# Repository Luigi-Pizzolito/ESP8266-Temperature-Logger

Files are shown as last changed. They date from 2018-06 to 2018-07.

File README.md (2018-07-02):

Add pictures from instructable
# ESP8266 Temperature Logger (in development)
A simple wireless temperature logger. Publishes data via GET requests.

- [ESP8266 Temperature Logger (in development)](#esp8266-temperature-logger-in-development)
    - [Planned Features (And Progress)](#planned-features-and-progress)
    - [About](#about)
        - [Uploading Data](#uploading-data)
        - [Power Saving](#power-saving)
        - [Configuration](#configuration)
    - [Useful Links and References](#useful-links-and-references)

## Planned Features (And Progress)
 - [X] Uploads
 - [X] Power Saving
 - [X] Configuration

## About
Designed to be simple and easy to use. Will simply log temperature at the specified interval and send the values over to a IOT Server.

### Uploading Data
To keep things simple, this data logger makes HTTP GET requests to upload it's data. It passes the temperature reading and supply voltage as arguments.

This makes for a extremely neat setup if it is paired with Google Forms, Google Sheets and IFTTT.
By opening up a Google Form, with text fields for temperature and voltage. You can link that form to a Google sheet, which automatically updates with every form response and can graph your data. Finally, submitting a form is done via a GET request, be it a complicated one. Therefore using IFTTT's maker webhooks. We can create an applet that takes a simple GET request from our ESP Datalogger and passes the values down to another request that submits the Google forms. Once this is set up, it works like a charm. Plus, live updates!

### Power Saving
Since this is a logger and will almost certainly spend most of it's time laying around not doing anything; we wan't to make it consume the least power as possible. This means that as soon as data is uploaded it immediatly goes back to deep sleep. Deep sleep turns all the ESP's internal modules off except for the RTC which wakes it back up. This plus removing the pesky red power led on a ESP-01 module gives excellent power saving.
But there's a catch, for the RTC to reset and wake up the ESP it needs an external interrupt. This means that we have to connect GPIO16(D0) to RESET. This would be easy on a ESP-12E, ESP-07 or NodeMCU but GPIO16 is not broken out on a ESP-01. So in order to access it you will have to attempt to solder a thin wire to the pin directly on the miniscule ESP chip. This is certainly the hardest part of making this logger, but it is do-able with just a standard soldering iron and a lot of patience.
By changing the interval between logs you can also improve the battery life. The longer the interval the longer it will last, but the fewer readings. You need to choose a interval large enough so that the power consumption is small, but small enough so that you can see any trends on the graph/data.

### Configuration
GPIO_3 or the RX Pin when connected to GND during start up enters config. mode. Where an access point called "ESP_Logger" with the password "wifilogger" is created. By connecting to it and visiting 192.168.4.1 you can open the configuration page and edit all the settings for your logger. Additionally you can edit the file system on 192.168.4.1/edit

## Useful Links and References
- ESP Info
    - Pinouts
        - [ESP-12 Pinout](https://esp8266.github.io/Arduino/versions/2.0.0/doc/esp12.png)
        - [ESP-01 Pinout](https://os.mbed.com/media/uploads/sschocke/esp8266-pinout_etch_copper_top.png)
    - General Guides
        - [Sparkfun Guide](https://learn.sparkfun.com/tutorials/esp8266-thing-hookup-guide/using-the-arduino-addon)
        - [Excellent Beginner's Guide](https://github.com/tttapa/ESP8266)
- GitHub Markdown Info
    - [Formatting and Syntax](https://help.github.com/articles/basic-writing-and-formatting-syntax/)
    - [Emoji Cheat Sheet](https://www.webpagefx.com/tools/emoji-cheat-sheet/)

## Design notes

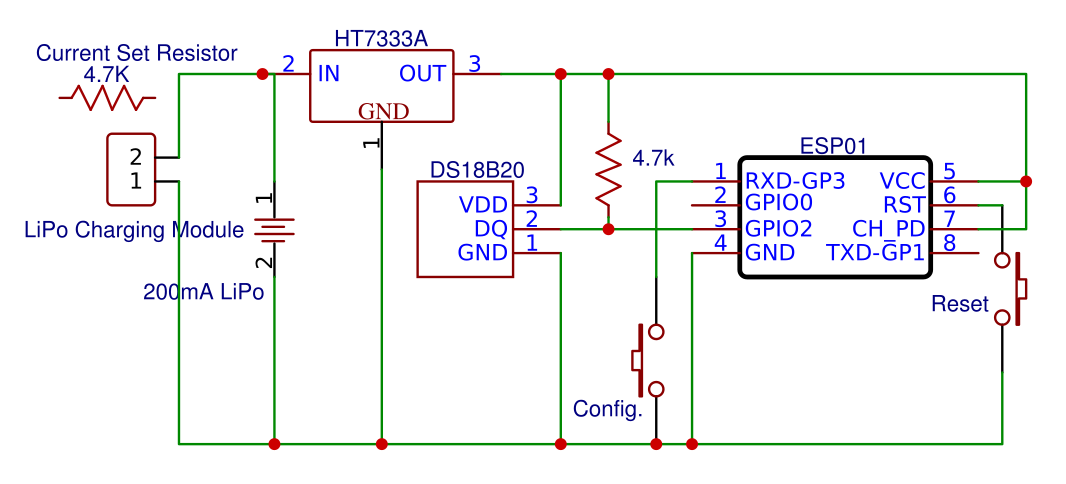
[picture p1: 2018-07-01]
Schematic/Schematic_IFTTT-Dash-Button_New-Schematic_20180702032907.png

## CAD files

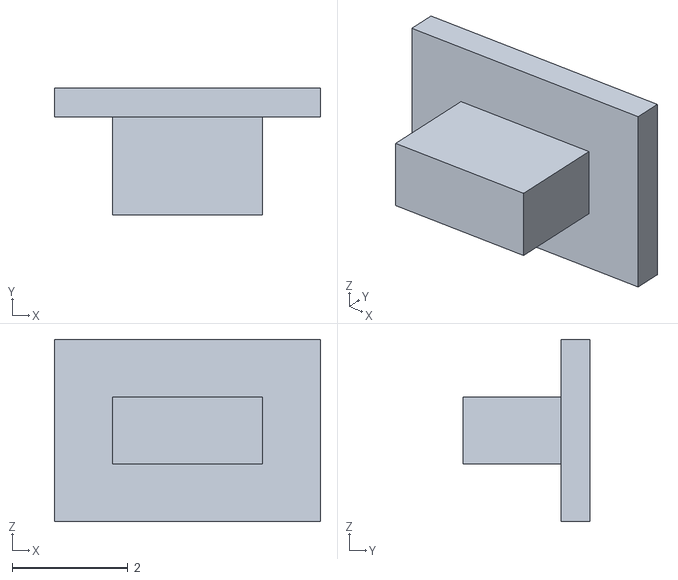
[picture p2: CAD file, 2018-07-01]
3D Printed Case/buttons.stl
4.60 x 2.20 x 3.15

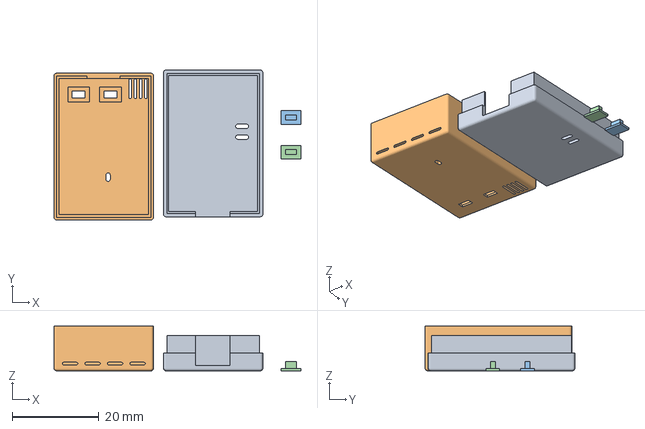
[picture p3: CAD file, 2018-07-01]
3D Printed Case/TinyTemp_Case.3mf
57.1 x 34.6 x 10.4 mm

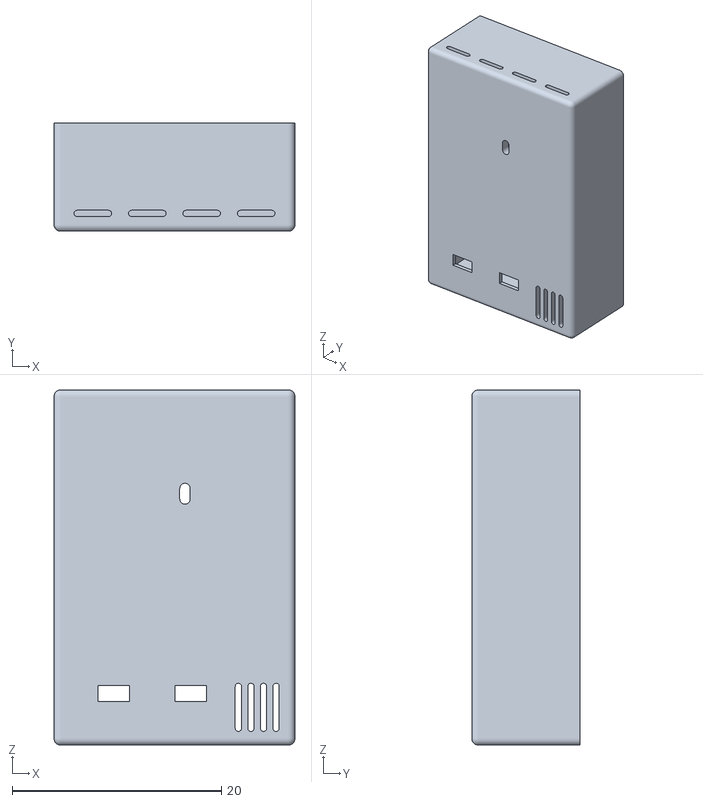
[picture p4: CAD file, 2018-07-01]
3D Printed Case/top_case.stl
23.0 x 10.4 x 33.9

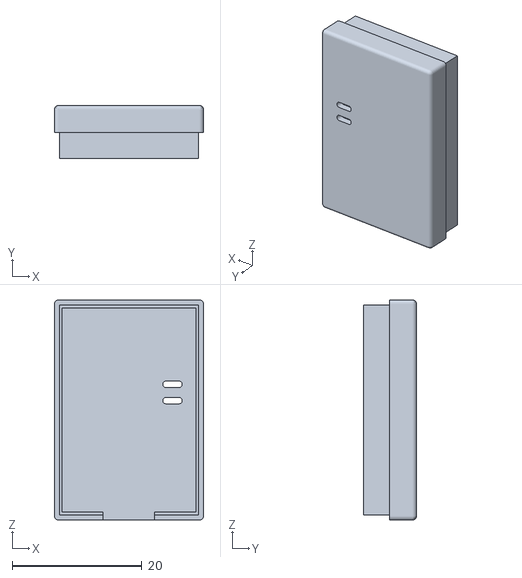
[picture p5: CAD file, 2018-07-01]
3D Printed Case/bottom_case.stl
23.0 x 8.15 x 33.9

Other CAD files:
3D Printed Case/case v18.f3d

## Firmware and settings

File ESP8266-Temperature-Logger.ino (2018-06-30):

/*
   Libraries needed
*/
//Normal Mode
#include <ESP8266WiFi.h>
#include <ArduinoJson.h>
//Config. Mode
#include <WiFiClient.h>
#include <ESP8266WebServer.h>
#include <FS.h>
//Temperature Sensing.
#include <OneWire.h>

/*
   Configurable Settings

   Connect CONFIG_PIN(Default GPIO_03[RX]) to GND during startup to enter Config. Mode:
      1. Connect to 'ESP_Logger' WiFi Access Point, with the password 'wifilogger'
      2. Visit http://192.168.4.1 to open the configuration page, or  http://192.168.4.1/edit to see the filesystem.
      3. After seeting your values, click on the 'Save' button then the 'Restart'
      4. Your logger is now configured.
*/
String ssid;
String password;
String host;
String url;
int wc_p;         // max. time in seconds to connect to wifi, before giving up
int gr_p;         // max. times of attemps to perform GET request, before giving up
bool s_vcc;       //wether to send VCC voltage as a parameter in the url request.
bool is_ip;       //wether host adress is IP
String vcc_parm;  //parameter to pass VCC voltage by.
String temp_parm; //parameter to pass temperature by.
long sleepTime;

//temp Sensing
float celsius;

/*
   System Variables
*/
#define NOT_DEBUG //wether to enable debug or to show indication lights instead
//Normal Mode
int failCount = 0;
ADC_MODE(ADC_VCC);
bool su_mode = true;
//Config. Mode
#define CONFIG_PIN 3
ESP8266WebServer server(80);
File fsUploadFile;
const char *APssid = "ESP_Logger";
const char *APpass = "wifilogger";
//Temp Sensing
OneWire ds(2); // on pin 2 (a ~4.7K resistor is necessary)

void setup()
{
  //start serial monitor, SPIFFS and Config. Pin
  pinMode(16, WAKEUP_PULLUP);
  WiFi.persistent(false);
  Serial.begin(115200);
  pinMode(CONFIG_PIN, INPUT_PULLUP);
  delay(10);
  SPIFFS.begin();
  Serial.println();
  Serial.println("Logger Booting...");

  //read Config. Pin
  su_mode = !digitalRead(CONFIG_PIN);
  if (su_mode)
  {

//start Config. Mode
#ifdef NOT_DEBUG
    pinMode(LED_BUILTIN, OUTPUT);
    digitalWrite(LED_BUILTIN, LOW);
#endif
    Serial.println("Entering Config. Mode!");

    //start WiFi Access Point
    Serial.println("Configuring Access Point...");
    WiFi.mode(WIFI_AP_STA);
    WiFi.softAP(APssid, APpass);

    IPAddress myIP = WiFi.softAPIP();
    Serial.print("AP IP Address: ");
    Serial.println(myIP);

    //start HTTP server

    //edit pages
    server.on("/list", HTTP_GET, handleFileList);
    server.on("/edit", HTTP_GET, []() {
      if (!handleFileRead("/edit.htm"))
        server.send(404, "text/plain", "File Not Found");
    });
    server.on("/edit", HTTP_PUT, handleFileCreate);
    server.on("/edit", HTTP_DELETE, handleFileDelete);
    server.on("/edit", HTTP_POST, []() { server.send(200, "text/plain", ""); }, handleFileUpload);

    //pages from SPIFFS
    server.onNotFound([]() {
      if (!handleFileRead(server.uri()))
      {
        server.send(404, "text/plain", "File Not Found");
      }
    });

    //temp serving page
    server.on("/temp", HTTP_GET, []() { celsius = getTemp(); server.send(200, "text/plain", String(celsius)); });
    server.on("/temp/", HTTP_GET, []() { celsius = getTemp(); server.send(200, "text/plain", String(celsius)); });

    server.begin();
    Serial.println("HTTP Server Started");
  }
  else
  {
    //start Normal Mode
    Serial.println("SPIFFS Content: ");
    {
      Dir dir = SPIFFS.openDir("/");
      while (dir.next())
      {
        String fileName = dir.fileName();
        size_t fileSize = dir.fileSize();
        Serial.printf("FS File: %s, size: %s\n", fileName.c_str(), formatBytes(fileSize).c_str());
      }
      Serial.printf("\n");
    }

    //read and parse config.json from SPIFFS
    readConfig();

    //connect to WiFi
    Serial.println();
    Serial.println();
    Serial.print("Connecting to ");
    Serial.println(ssid);

    WiFi.mode(WIFI_STA);
    WiFi.begin(ssid.c_str(), password.c_str());

    while (WiFi.status() != WL_CONNECTED)
    {
      delay(500);
      Serial.print(".");
      //if we are taking too long to connect to WiFi give up.
      failCount++;
      if (failCount == wc_p * 2)
      {
        Serial.print("Session Terminated. Giving up After ");
        Serial.print(wc_p);
        Serial.println(" Tries Connecting to WiFi.");
        delay(20);
        fail();
        sleepNow();
      }
    }

    Serial.println("");
    Serial.println("WiFi connected");
    Serial.print("IP Address: ");
    Serial.println(WiFi.localIP());
    failCount = 0;
  }
}

void loop()
{
  if (su_mode)
  {
    server.handleClient();
  }
  else
  {
    //if we have tried too many times to make a GET Request give up.
    ++failCount;
    if (failCount == gr_p + 1)
    {
      Serial.print("Session Terminated. Giving up After ");
      Serial.print(gr_p);
      Serial.println(" Tries Doing the GET Request.");
      delay(20);
      fail();
      sleepNow();
    }

    Serial.print("Try: ");
    Serial.println(failCount);
    Serial.print("Connecting to ");
    Serial.println(host);

    //try to connect to the host with TCP
    WiFiClient client;
    const int httpPort = 80;
    if (is_ip)
    {
      IPAddress addr;
      if (addr.fromString(host))
      {
        if (!client.connect(addr, httpPort))
        {
          //try again if the connection fails.
          Serial.println("Connection To IP Failed");
          delay(10);
          return;
        }
      }
      else
      {
        Serial.println("Failed to Convert IP String to IP Address.");
        while (1)
          ;
      }
    }
    else
    {
      if (!client.connect(host.c_str(), httpPort))
      {
        //try again if the connection fails.
        Serial.println("Connection Failed");
        delay(10);
        return;
      }
    }

    //create the URI for the request
    url += "?";

    if (s_vcc)
    {
      //read vcc
      url += vcc_parm;
      url += "=";
      uint32_t getVcc = ESP.getVcc();
      String VccVol = String((getVcc / 1000U) % 10) + "." + String((getVcc / 100U) % 10) + String((getVcc / 10U) % 10) + String((getVcc / 1U) % 10);
      url += VccVol;
      url += "&";
    }
    //read temperature
    url += temp_parm;
    url += "=";
    celsius = getTemp();
    url += String(celsius);

    //request url to server
    Serial.print("Requesting URL: ");
    Serial.println(url);

    client.print(String("GET ") + url + " HTTP/1.1\r\n" +
                 "Host: " + host.c_str() + "\r\n" +
                 "Connection: close\r\n\r\n");

    unsigned long timeout = millis();
    while (client.available() == 0)
    {
      if (millis() - timeout > 60000)
      {
        //give up if the server takes too long to reply.
        Serial.println(">>> Client Timeout !");
        client.stop();
        //return;
        sleepNow();
      }
    }

    //print response to serial
    while (client.available())
    {
      String line = client.readStringUntil('\r');
      Serial.print(line);
    }
    //finish request and close connections
    client.stop();
    Serial.println();
    Serial.println("Closing Connection");

    //enter Deep Sleep
    // Serial.println("Entering Deep Sleep");
    delay(100);
    yay();
    sleepNow();
  }
}

/*
   Universal Functions
*/

//temp reading
float getTemp()
{
  byte i;
  byte present = 0;
  byte type_s;
  byte data[12];
  byte addr[8];
  float celsius, fahrenheit;
  int failCountWire = 0;

  if (!ds.search(addr))
  {
    failCountWire++;
    if (failCountWire == 5)
    {
      Serial.print("Reding Terminated. Giving up After 5 Tries Reading Sensor...");
      delay(20);
      fail();
      sleepNow();
    }
    Serial.println("No more addresses.");
    Serial.println();
    ds.reset_search();
    delay(250);
    // return;
  }

  Serial.print("ROM =");
  for (i = 0; i < 8; i++)
  {
    Serial.write(' ');
    Serial.print(addr[i], HEX);
  }

  if (OneWire::crc8(addr, 7) != addr[7])
  {
    Serial.println("CRC is not valid!");
    delay(20);
    fail();
    sleepNow();
    // return;
  }
  Serial.println();

  // the first ROM byte indicates which chip
  switch (addr[0])
  {
  case 0x10:
    Serial.println("  Chip = DS18S20"); // or old DS1820
    type_s = 1;
    break;
  case 0x28:
    Serial.println("  Chip = DS18B20");
    type_s = 0;
    break;
  case 0x22:
    Serial.println("  Chip = DS1822");
    type_s = 0;
    break;
  default:
    Serial.println("Device is not a DS18x20 family device.");
    delay(20);
    fail();
    sleepNow();
  }

  ds.reset();
  ds.select(addr);
  ds.write(0x44, 1); // start conversion, with parasite power on at the end

  delay(1000); // maybe 750ms is enough, maybe not
  // we might do a ds.depower() here, but the reset will take care of it.

  present = ds.reset();
  ds.select(addr);
  ds.write(0xBE); // Read Scratchpad

  Serial.print("  Data = ");
  Serial.print(present, HEX);
  Serial.print(" ");
  for (i = 0; i < 9; i++)
  { // we need 9 bytes
    data[i] = ds.read();
    Serial.print(data[i], HEX);
    Serial.print(" ");
  }
  Serial.print(" CRC=");
  Serial.print(OneWire::crc8(data, 8), HEX);
  Serial.println();

  int16_t raw = (data[1] << 8) | data[0];
  if (type_s)
  {
    raw = raw << 3; // 9 bit resolution default
    if (data[7] == 0x10)
    {
      // "count remain" gives full 12 bit resolution
      raw = (raw & 0xFFF0) + 12 - data[6];
    }
  }
  else
  {
    byte cfg = (data[4] & 0x60);
    // at lower res, the low bits are undefined, so let's zero them
    if (cfg == 0x00)
      raw = raw & ~7; // 9 bit resolution, 93.75 ms
    else if (cfg == 0x20)
      raw = raw & ~3; // 10 bit res, 187.5 ms
    else if (cfg == 0x40)
      raw = raw & ~1; // 11 bit res, 375 ms
    //// default is 12 bit resolution, 750 ms conversion time
  }
  celsius = (float)raw / 16.0;
  return celsius;
}

//enter deep Sleep
void sleepNow()
{
  yield();
  //delay(120000);
  WiFi.disconnect();
  WiFi.mode(WIFI_OFF);
  // WiFi.forceSleepBegin();

  Serial.println("Entering Deep sleep...");
  delay(300);
  yield();
  ESP.deepSleep(sleepTime * 60 * 1000000, WAKE_RF_DEFAULT);
  delay(1000);
}

void fail()
{
  //something has gone wrong, blink an indicator on the LED.
  pinMode(LED_BUILTIN, OUTPUT);
  digitalWrite(LED_BUILTIN, LOW);
  delay(250);
  digitalWrite(LED_BUILTIN, HIGH);
  delay(250);
  digitalWrite(LED_BUILTIN, LOW);
  delay(250);
  digitalWrite(LED_BUILTIN, HIGH);
  delay(250);
  digitalWrite(LED_BUILTIN, LOW);
  delay(250);
  digitalWrite(LED_BUILTIN, HIGH);
  delay(250);
  digitalWrite(LED_BUILTIN, LOW);
  delay(250);
  digitalWrite(LED_BUILTIN, HIGH);
  delay(250);
  digitalWrite(LED_BUILTIN, LOW);
  delay(250);
  digitalWrite(LED_BUILTIN, HIGH);
  delay(250);
  digitalWrite(LED_BUILTIN, LOW);
  delay(500);
  digitalWrite(LED_BUILTIN, HIGH);
}

void yay()
{
  //everything worked, blink an indicator on the LED.
  pinMode(LED_BUILTIN, OUTPUT);
  digitalWrite(LED_BUILTIN, LOW);
  delay(1500);
  digitalWrite(LED_BUILTIN, HIGH);
  delay(250);
  digitalWrite(LED_BUILTIN, LOW);
  delay(350);
  digitalWrite(LED_BUILTIN, HIGH);
}

void readConfig()
{
  //read config.json and load configuration to variables.
  File configFile = SPIFFS.open("/config.jsn", "r");
  if (!configFile)
  {
    Serial.println("Failed to Open Config. File");
    delay(20);
    fail();
    sleepNow();
  }
  size_t size = configFile.size();
  if (size > 1024)
  {
    Serial.println("Config. File Size is too Large");
    delay(20);
    fail();
    sleepNow();
  }
  std::unique_ptr<char[]> buf(new char[size]);
  configFile.readBytes(buf.get(), size);
  StaticJsonBuffer<300> jsonBuffer;
  JsonObject &json = jsonBuffer.parseObject(buf.get());
  if (!json.success())
  {
    Serial.println("Failed to Parse config. File");
    delay(20);
    fail();
    sleepNow();
  }

  ssid = (const char *)json["ssid"];
  password = (const char *)json["pass"];
  host = (const char *)json["host"];
  url = (const char *)json["uri"];
  wc_p = json["wc_p"];
  gr_p = json["gr_p"];
  s_vcc = json["s_vcc"];
  is_ip = json["is_ip"];
  vcc_parm = (const char *)json["vcc_p"];
  temp_parm = (const char *)json["temp_p"];
  sleepTime = json["sleep"];

  Serial.println("Parsed JSON Config.");
  Serial.print("Loaded ssid: ");
  Serial.println(ssid);
  Serial.print("Loaded password: ");
  Serial.println(password);
  Serial.print("Loaded host: ");
  Serial.println(host);
  Serial.print("Loaded IsIP: ");
  Serial.println(is_ip);
  Serial.print("Loaded uri: ");
  Serial.println(url);
  Serial.print("Loaded WiFi Connect Persistance: ");
  Serial.println(wc_p);
  Serial.print("Loaded GET Request Persistance: ");
  Serial.println(gr_p);
  Serial.print("Loaded Send VCC: ");
  Serial.println(s_vcc);
  Serial.print("Loaded VCC Param.: ");
  Serial.println(vcc_parm);
  Serial.print("Loaded Temp. Param.: ");
  Serial.println(temp_parm);
  Serial.print("Loaded Sleep Time: ");
  Serial.println(sleepTime);
  Serial.println();
}

/*
   Config. Mode Functions
*/

//edit functions
String formatBytes(size_t bytes)
{
  if (bytes < 1024)
  {
    return String(bytes) + "B";
  }
  else if (bytes < (1024 * 1024))
  {
    return String(bytes / 1024.0) + "KB";
  }
  else if (bytes < (1024 * 1024 * 1024))
  {
    return String(bytes / 1024.0 / 1024.0) + "MB";
  }
  else
  {
    return String(bytes / 1024.0 / 1024.0 / 1024.0) + "GB";
  }
}

String getContentType(String filename)
{
  if (server.hasArg("download"))
    return "application/octet-stream";
  else if (filename.endsWith(".htm"))
    return "text/html";
  else if (filename.endsWith(".html"))
    return "text/html";
  else if (filename.endsWith(".css"))
    return "text/css";
  else if (filename.endsWith(".js"))
    return "application/javascript";
  else if (filename.endsWith(".png"))
    return "image/png";
  else if (filename.endsWith(".gif"))
    return "image/gif";
  else if (filename.endsWith(".jpg"))
    return "image/jpeg";
  else if (filename.endsWith(".ico"))
    return "image/x-icon";
  else if (filename.endsWith(".xml"))
    return "text/xml";
  else if (filename.endsWith(".pdf"))
    return "application/x-pdf";
  else if (filename.endsWith(".zip"))
    return "application/x-zip";
  else if (filename.endsWith(".gz"))
    return "application/x-gzip";
  return "text/plain";
}

bool handleFileRead(String path)
{
  Serial.println("handleFileRead: " + path);
  if ((path == "/") && (server.argName(0) == "restart" && server.arg(0) == "true"))
  {
    Serial.println("requested reset from admin page!");
    server.send(200, "text/plain", "Restarting!");
#ifdef NOT_DEBUG
    digitalWrite(LED_BUILTIN, HIGH);
#endif
    delay(200);
    wdt_reset();
    ESP.restart();
    while (1)
    {
      wdt_reset();
    }
    //WiFi.forceSleepBegin(); wdt_reset(); ESP.restart(); while (1)wdt_reset();
  }
  if (path.endsWith("/"))
    path += "index.htm";
  String contentType = getContentType(path);
  String pathWithGz = path + ".gz";
  if (SPIFFS.exists(pathWithGz) || SPIFFS.exists(path))
  {
    if (SPIFFS.exists(pathWithGz))
      path += ".gz";
    File file = SPIFFS.open(path, "r");
    size_t sent = server.streamFile(file, contentType);
    file.close();
    return true;
  }
  return false;
}

void handleFileUpload()
{
  if (server.uri() != "/edit")
    return;
  HTTPUpload &upload = server.upload();
  if (upload.status == UPLOAD_FILE_START)
  {
    String filename = upload.filename;
    if (!filename.startsWith("/"))
      filename = "/" + filename;
    Serial.print("handleFileUpload Name: ");
    Serial.println(filename);
    fsUploadFile = SPIFFS.open(filename, "w");
    filename = String();
  }
  else if (upload.status == UPLOAD_FILE_WRITE)
  {
    //Serial.print("handleFileUpload Data: "); Serial.println(upload.currentSize);
    if (fsUploadFile)
      fsUploadFile.write(upload.buf, upload.currentSize);
  }
  else if (upload.status == UPLOAD_FILE_END)
  {
    if (fsUploadFile)
      fsUploadFile.close();
    Serial.print("handleFileUpload Size: ");
    Serial.println(upload.totalSize);
  }
}

void handleFileDelete()
{
  if (server.args() == 0)
    return server.send(500, "text/plain", "BAD ARGS");
  String path = server.arg(0);
  Serial.println("handleFileDelete: " + path);
  if (path == "/")
    return server.send(500, "text/plain", "BAD PATH");
  if (!SPIFFS.exists(path))
    return server.send(404, "text/plain", "FileNotFound");
  SPIFFS.remove(path);
  server.send(200, "text/plain", "");
  path = String();
}

void handleFileCreate()
{
  if (server.args() == 0)
    return server.send(500, "text/plain", "BAD ARGS");
  String path = server.arg(0);
  Serial.println("handleFileCreate: " + path);
  if (path == "/")
    return server.send(500, "text/plain", "BAD PATH");
  if (SPIFFS.exists(path))
    return server.send(500, "text/plain", "FILE EXISTS");
  File file = SPIFFS.open(path, "w");
  if (file)
    file.close();
  else
    return server.send(500, "text/plain", "CREATE FAILED");
  server.send(200, "text/plain", "");
  path = String();
}

void handleFileList()
{
  if (!server.hasArg("dir"))
  {
    server.send(500, "text/plain", "BAD ARGS");
    return;
  }

  String path = server.arg("dir");
  Serial.println("handleFileList: " + path);
  Dir dir = SPIFFS.openDir(path);
  path = String();

  String output = "[";
  while (dir.next())
  {
    File entry = dir.openFile("r");
    if (output != "[")
      output += ',';
    bool isDir = false;
    output += "{\"type\":\"";
    output += (isDir) ? "dir" : "file";
    output += "\",\"name\":\"";
    output += String(entry.name()).substring(1);
    output += "\"}";
    entry.close();
  }

  output += "]";
  server.send(200, "text/json", output);
}
